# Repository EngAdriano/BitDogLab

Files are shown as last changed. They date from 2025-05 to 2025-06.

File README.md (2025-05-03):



# BitDogLab
An open-source hardware project designed to promote learning in embedded systems, programming, and electronics.

BitDogLab, an initiative of the School Project 4.0 at Unicamp, is an educational tool devoted to electronics and computing. Based on Raspberry Pi Pico H or W, it allows users to explore, assemble, and program using components mounted on its board and also external ones connected in an organized and secure manner. Meticulously selected, the components foster hands-on learning, encouraging users to enhance programming and electronics skills synergistically and progressively. This enriching platform offers a vibrant experience, immersing users in a colourful, auditory, and synesthetic learning environment. Additionally, BitDogLab is optimized for programming assisted by large language models (LLM), like GPT-4, facilitating a more intuitive learning guided by a tireless tutor. Aimed at pre-university education, BitDogLab aims to catalyze the incorporation of educational technology, providing a robust and flexible tool uniquely integrated into students' learning journey.

A hallmark of BitDogLab is that its project is entirely open, allowing it to be freely copied, manufactured, assembled, and improved by users. More information at: https://github.com/Fruett/BitDogLab

This repository holds open-source design files for BitDogLab, an educational STEAM tool. It includes various components like LEDs, buzzers, buttons, and more, promoting collaborative modification and enhancement of STEAM education.

## License
This project is licensed under the CERN Open Hardware Licence Version 2 - Strongly Reciprocal (CERN-OHL-S).
For more details, see the `LICENSE` file or visit [https://cern.ch/cern-ohl](https://cern.ch/cern-ohl).

## Github structure
```bash
├───Firmware "The following files are firmware that should work on BitDogLab"
│   ├───BitDogLab.uf2 "supported on the Raspberry pi pico H version"
│   ├───BitDogLab_W.uf2 "supported on the Raspberry pi pico W (wireless version)"
│   ├───clean.uf2 "Firmware to clean BitDogLab"
│   └───main.py "This is a software example for debug alls board features"
├───kicad "The following files are Hardwares informations"
│   ├───bitdoglab "Schematic, layout and gerber files of DIY version"
│   ├───bitdoglabsmd "Schematic, layout and gerber files of SMD version"
│   └───libs "3D cads, symbols and footprints for bitdoglab DIY"
└───libs "thirdy party libs for softwares"
```

## Firmware v1.0 da BitDogLab with Micropython 1.22.1
### BitDogLab Firmware was compiled on 02/04/2024 and already includes the following 3rd libs:
* ahtx0 (Sensor de temperatura/umidade AHT10 i2c)
* bh1750 (Sensor de luminosidade i2c)
* ssd1306 (Oled i2c)

#### To enter ther bootloader mode, hold bootsel button on the raspberry pi. After, copy the new firmware. If you want to guarantee a new instalation, copy clean.uf2 before.

### [Firmware download](https://github.com/Fruett/BitDogLab/tree/main/Firmware)

## Version 5.4 (DIY)



### Release notes v5.4
* Changing GPIO4 by GPIO10 in Buzzer B
* Changing pin4 GPIO10 by GPIO8 in IDC connector
* Changing pin8 with GPIO8 by GPIO4 in IDC connector
* Changing A,B buttons footprints by 12mm footprint 
* Adding 10k pulldown resistor in batt charging mosfet
### Gerber files for fabrication:
* ADD

### Bill Of material (BOM) for PCB external modules version
* https://docs.google.com/spreadsheets/d/10G9U2lKZ8DwIemRyy8-OiIrZH5e2oOeCSGOkK32-5-8/edit?usp=sharing

## Version 5.3 (PCB SMD version)

SMD PCB version top Side view




SMD PCB version bottom Side view




KiCAD PCB layout: 
* [Panel PCB](https://github.com/Fruett/BitDogLab/blob/main/kicad/bitdoglabsmd/bitdoglab_painel/bitdoglab_painel.kicad_pcb)
* [SMD PCB with Raspberry Pi Pico W](https://github.com/Fruett/BitDogLab/blob/main/kicad/bitdoglabsmd/bitdoglab_main/bitdoglab_smd.kicad_pcb)

Gerber files for fabrication (2024-03-13): 
* [v5.3 panel fabrication files](https://github.com/Fruett/BitDogLab/blob/main/kicad/bitdoglabsmd/bitdoglab_painel/bitdoglab_painel-fabrication-files.zip)
* [v5.3 main fabrication files](https://github.com/Fruett/BitDogLab/blob/main/kicad/bitdoglabsmd/bitdoglab_main/bitdoglab_smd-fabrication-files.zip)

Bill Of material -BOM (2024-03-13): 
* [BOM v5.3 spreadsheet](https://docs.google.com/spreadsheets/d/10G9U2lKZ8DwIemRyy8-OiIrZH5e2oOeCSGOkK32-5-8/edit#gid=1766402277)
* [BOM v5.3 CSV](https://github.com/Fruett/BitDogLab/blob/main/kicad/bitdoglabsmd/bitdoglab_main/bitdoglab_smd.csv)

## Hardware Data Base or Banco de Informação de Hardware
English: https://docs.google.com/document/d/1bf_AKWDJkhcB7H8UVbGR0fSsl2v-2yXr_iV1fd5NWmE/edit?usp=sharing

Português: https://docs.google.com/document/d/13-68OqiU7ISE8U2KPRUXT2ISeBl3WPhXjGDFH52eWlU/edit?usp=sharing

#### Sponsor: IEEE-EDS: https://eds.ieee.org/chapters/programs-and-stem-outreach-resources
#### Sponsor: CNPq - INCT - Namitec: https://web.facebook.com/INCTNAMITEC/?_rdc=1&_rdr
#### Supporter: [Hardware Innovation Technologies (Paulinia/SP/Brazil)](http://www.hwit.com.br/)

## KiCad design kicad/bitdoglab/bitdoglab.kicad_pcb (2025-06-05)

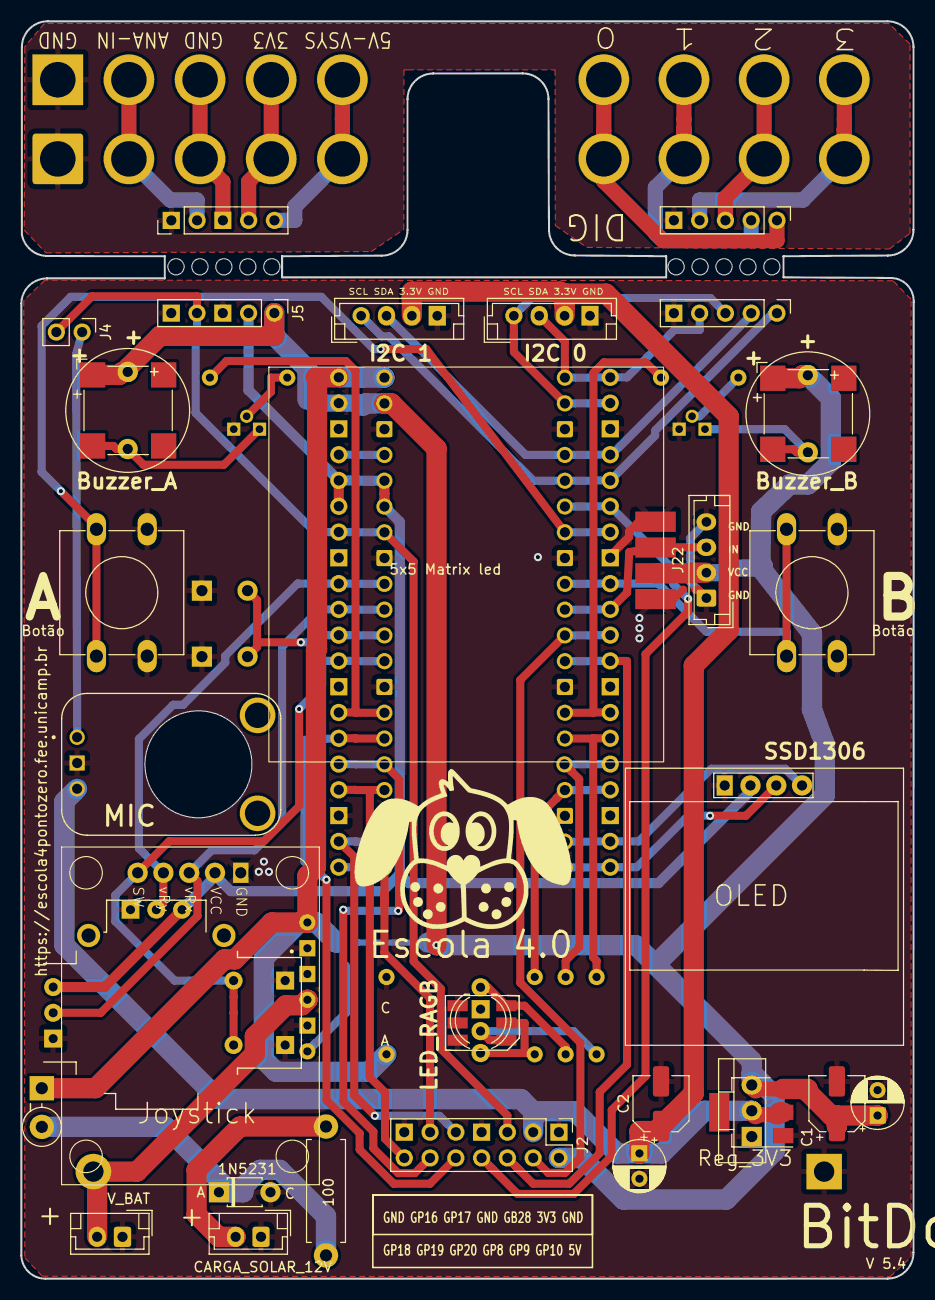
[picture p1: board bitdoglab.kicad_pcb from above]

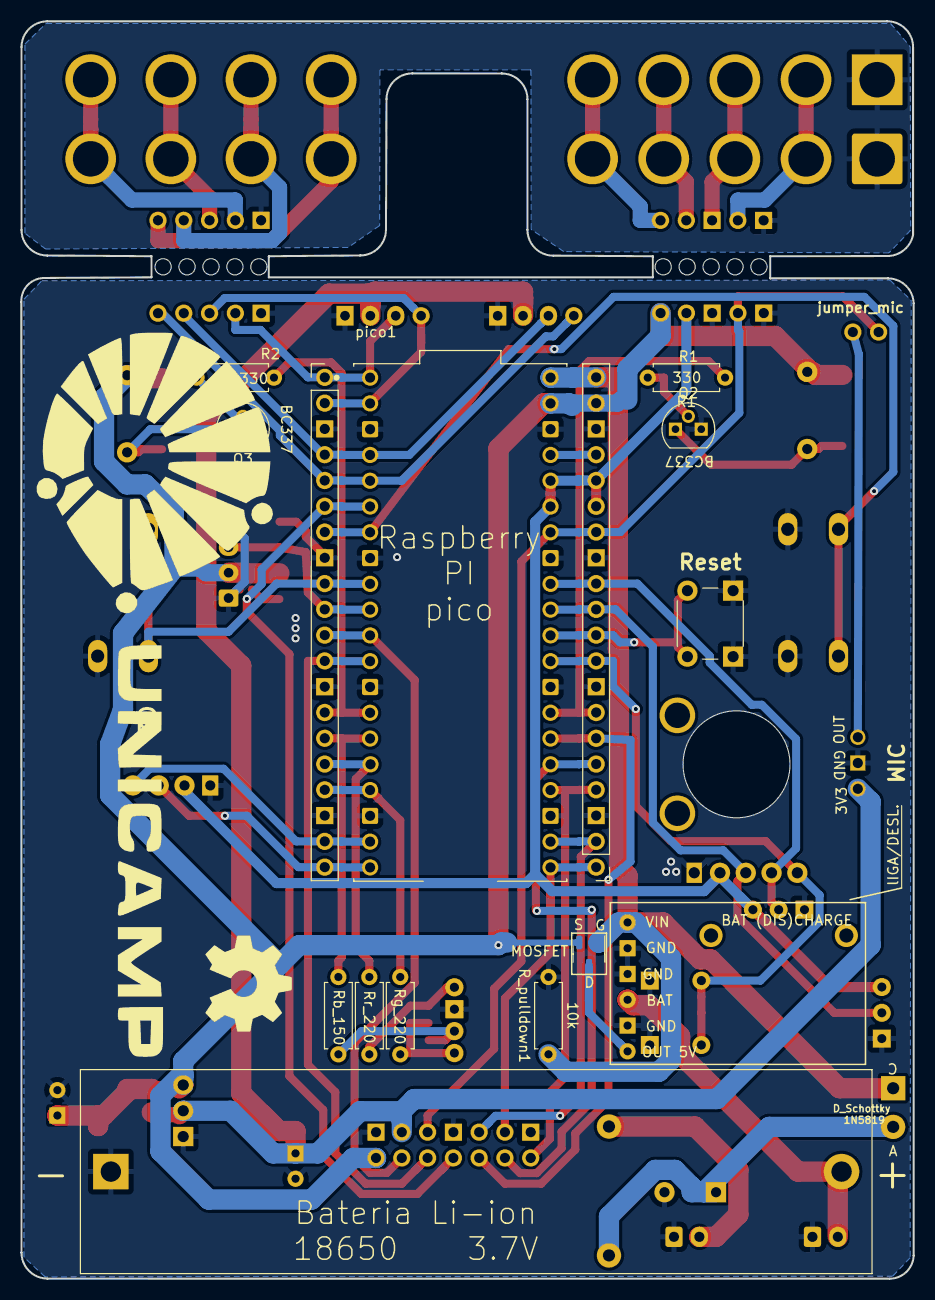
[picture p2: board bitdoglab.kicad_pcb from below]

Board: 2 copper layers, 87.9 x 123.9 mm, 60 parts (17 on the bottom side), 54 nets.

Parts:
BT1: Battery_Cell; BatteryHolder_MPD_BH-18650-PC2
BZ1: Buzzer_A; Buzzer_12x9.5RM7.6
BZ2: Buzzer_A_SMD; MagneticBuzzer_CUI_CMT-8504-100-SMT
BZ3: Buzzer_B; Buzzer_12x9.5RM7.6
BZ4: Buzzer_B_SMD; MagneticBuzzer_CUI_CMT-8504-100-SMT
C1, C2: C_smd; CP_Elec_5x5.9
C3, C4: C_pth; CP_Radial_D5.0mm_P2.50mm
CARGA_SOLAR1: CARGA_SOLAR_12V; JST_EH_B2B-EH-A_1x02_P2.50mm_Vertical
Charge_DisCharge1: BAT (DIS)CHARGE; Charger2A
D1: LED_RGB_SMD; LED_RGB_5050-6
D2: LED_RAGB; LED_D5.0mm-4_RGB_Wide_Pins
D3: 1N5231; D_T-1_P5.08mm_Horizontal
D4: D_Schottky; D_DO-15_P3.81mm_Vertical_KathodeUp
G1: LOGO; logo bitDog 25mm
G2: LOGO; unicamp V2A
G3: LOGO
J1, J3: Conn_01x20_Socket; PinHeader_1x20_P2.54mm_Vertical
J2: conector_idc; PinHeader_2x07_P2.54mm_Vertical
J4: jumper_mic; PinHeader_1x02_P2.54mm_Vertical
J5, J6, J12, J13: Conn_01x05_Pin; PinHeader_1x05_P2.54mm_Vertical
J7, J9: GND; SolderWire-2sqmm_1x02_P7.8mm_D2mm_OD3.9mm
J8: ANA-IN; SolderWire-2sqmm_1x02_P7.8mm_D2mm_OD3.9mm
J10: 3V3; SolderWire-2sqmm_1x02_P7.8mm_D2mm_OD3.9mm
J11: 5V-VSYS; SolderWire-2sqmm_1x02_P7.8mm_D2mm_OD3.9mm
J14: 5x5 Matrix led; Ws2812_led_5050_rgb_5x5
J15: 0; SolderWire-2sqmm_1x02_P7.8mm_D2mm_OD3.9mm
J16: 1; SolderWire-2sqmm_1x02_P7.8mm_D2mm_OD3.9mm
J17: 2; SolderWire-2sqmm_1x02_P7.8mm_D2mm_OD3.9mm
J18: 3; SolderWire-2sqmm_1x02_P7.8mm_D2mm_OD3.9mm
J19: JOYSTICK; ky-023
J20, J21, J22: Conn_01x04_Pin; JST_EH_B4B-EH-A_1x04_P2.50mm_Vertical
JOY1: JOYSTICK; XDCR_COM-09032
OLED1: SSD1306; 128x64OLED
Q1: DMG2305UX-13; SOT-23-3
Q2, Q3: BC337; TO-92
R1, R2: 330; R_Axial_DIN0207_L6.3mm_D2.5mm_P7.62mm_Horizontal
R_1W1: 100; R_Axial_DIN0411_L9.9mm_D3.6mm_P12.70mm_Horizontal
R_pulldown1: 10k; R_Axial_DIN0207_L6.3mm_D2.5mm_P7.62mm_Horizontal
Rb_150: 150; R_Axial_DIN0207_L6.3mm_D2.5mm_P7.62mm_Horizontal
Reg_3V3: 3.3v_smd; SOT-223
Rg_220: 220; R_Axial_DIN0207_L6.3mm_D2.5mm_P7.62mm_Horizontal
Rr_220: 220; R_Axial_DIN0207_L6.3mm_D2.5mm_P7.62mm_Horizontal
SW1: Reset; SW_PUSH_6mm
SW2, SW3: Botão; SW_PUSH-12mm
U1: 3.3v_tht; TO-220-3_Vertical
U4: MIC; MODULE_1063
V_BAT1: V_BAT; JST_EH_B2B-EH-A_1x02_P2.50mm_Vertical
pico1: SC0918; MODULE_SC0918

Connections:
3.3_OUT: J3.15, J3.16, J5.2, J19.2, JOY1.H1, JOY1.V1, OLED1.2 (VCC), pico1.35 (ADC_VREF), pico1.36 (3V3_OUT)
3.3_OUT_EXT: J6.4, J10.1, J10.2
+3.3V: C2.1, C4.1, J2.3, J20.3, J21.3, Reg_3V3.2 (VO), U1.2, U4.3 (VCC)
/AGND_EXT: J6.3, J9.1, J9.2
/GND_EXT: J6.1, J7.1, J7.2, J13.5
/GP0: J1.1, J12.4, J21.2, pico1.1 (GP0)
/GP0_EXT: J13.4, J18.1, J18.2
/GP01: J1.2, J12.3, J21.1, pico1.2 (GP1)
/GP01_EXT: J13.3, J17.1, J17.2
/GP02: J1.4, J12.2, J20.2, pico1.4 (GP2)
/GP02_EXT: J13.2, J16.1, J16.2
/GP03: J1.5, J12.1, J20.1, pico1.5 (GP3)
/GP03_EXT: J13.1, J15.1, J15.2
/GP04: J1.6, J2.8, pico1.6 (GP4)
/GP08: J1.11, J2.4, pico1.11 (GP8)
/GP09: J1.12, J2.6, pico1.12 (GP9)
/GP10: J1.14, R2.1, pico1.14 (GP10)
/GP11: J1.15, Rb_150.2, pico1.15 (GP11)
/GP12: J1.16, Rr_220.2, pico1.16 (GP12)
/GP13: J1.17, Rg_220.2, pico1.17 (GP13)
/GP16: J2.11, J3.1, pico1.21 (GP16)
/GP17: J2.9, J3.2, pico1.22 (GP17)
/GP18: J2.14, J3.4, pico1.24 (GP18)
/GP19: J2.12, J3.5, pico1.25 (GP19)
/GP20: J2.10, J3.6, pico1.26 (GP20)
/GP28: J2.5, J3.14, J4.2, J5.4, pico1.34 (GP28)
/GP28_EXT: J6.2, J8.1, J8.2
/in: J1.10, J14.2, J22.3, pico1.10 (GP7)
/pino_07: J1.7, SW2.1, pico1.7 (GP5)
/pino_09: J1.9, SW3.1, pico1.9 (GP6)
/pino_19: J1.19, OLED1.4 (SDA), pico1.19 (GP14)
/pino_20: J1.20, OLED1.3 (SCL), pico1.20 (GP15)
/pino_27: J3.7, R1.1, pico1.27 (GP21)
/pino_29: J3.9, J19.5, JOY1.B2A, JOY1.B2B, pico1.29 (GP22)
/pino_30: J3.10, SW1.1, pico1.30 (RUN)
/pino_31: J3.11, J19.3, JOY1.H2, pico1.31 (GP26)
/pino_32: J3.12, J19.4, JOY1.V2, pico1.32 (GP27)
/pino_37: J3.17, pico1.37 (3V3_EN)
GNDREF: BT1.2 (-), C1.2, C2.2, C3.2, C4.2, CARGA_SOLAR1.1, Charge_DisCharge1.2 (GND), Charge_DisCharge1.4 (GND), Charge_DisCharge1.5 (GND), D1.1 (RK), D1.2 (GK), D1.3 (BK), D2.2 (K), D3.2 (A), J1.3, J1.8, J1.13, J1.18, J2.1, J2.7, J2.13, J3.3, J3.8, J3.13, J3.18, J5.3, J5.5, J12.5, J14.1, J14.4, J19.1, J20.4, J21.4, J22.1, J22.4, JOY1.B1A, JOY1.B1B, JOY1.H3, JOY1.V3, OLED1.1 (GND), Q2.3 (E), Q3.3 (E), R_pulldown1.2, Reg_3V3.1 (ADJ), SW1.2, SW2.2, SW3.2, U1.1, U4.2 (GND), V_BAT1.1, pico1.3 (GND), pico1.8 (GND), pico1.13 (GND), pico1.18 (GND), pico1.23 (GND), pico1.28 (GND), pico1.33 (AGND), pico1.38 (GND)
unnamed: BZ1.2 (+), BZ2.2 (+), Q2.1 (C)
unnamed: BZ3.2 (+), BZ4.2 (+), Q3.1 (C)
unnamed: CARGA_SOLAR1.2, R_1W1.2
unnamed: Charge_DisCharge1.1 (OUT5V), Q1.3 (D)
unnamed: D1.4 (BA), D2.3 (BA), Rb_150.1
unnamed: D1.5 (GA), D2.4 (GA), Rg_220.1
unnamed: D1.6 (RA), D2.1 (RA), Rr_220.1
unnamed: D3.1 (K), D4.2 (A), R_1W1.1
unnamed: J4.1, U4.1 (OUT)
unnamed: Q2.2 (B), R1.2
unnamed: Q3.2 (B), R2.2
VBUS: Charge_DisCharge1.6 (VIN), D4.1 (K), J3.20, Q1.1 (G), R_pulldown1.1, pico1.40 (VBUS)
VSYS: BZ1.1 (-), BZ2.1 (-), BZ3.1 (-), BZ4.1 (-), C1.1, C3.1, J2.2, J3.19, J5.1, J14.3, J22.2, Q1.2 (S), Reg_3V3.3 (VI), U1.3, pico1.39 (VSYS)
VSYS_EXT: J6.5, J11.1, J11.2
V_BAT +: BT1.1 (+), Charge_DisCharge1.3 (BAT), V_BAT1.2

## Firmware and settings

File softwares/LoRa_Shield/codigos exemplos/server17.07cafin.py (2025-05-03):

from machine import Pin, SoftI2C,PWM
from time import sleep
from ulora import LoRa, ModemConfig, SPIConfig
from ssd1306 import SSD1306_I2C
import os
import time
#configuração do OLED
i2c = SoftI2C(scl = Pin(15),sda = Pin(14))
oled = SSD1306_I2C(128,64,i2c)

#LoRa parameters
RFM95_RST = 28 # pino reset lora
RFM95_SPIBUS = SPIConfig.rp2_0 # pinagem LoRa RM95 e Pico
RFM95_CS = 17 # Chip select
RFM95_INT = 20 # DIO0
RF95_FREQ = 915.0 # Frequencia de transmissao
RF95_POW = 20 # Potencia de transmissao
CLIENT_ADDRESS = 1 # endereço cliente
SERVER_ADDRESS =2 # endereço server
#função para receber os dados da comunicação LoRa
#arquivo para salvar as informações
verde = Pin(11, Pin.OUT) # verde
azul = Pin(12, Pin.OUT) # azul
vermelho = Pin(13, Pin.OUT) #vermelho

buzzer_pin = Pin(21, Pin.OUT)
buzzer_pwm = PWM(buzzer_pin)
ex_notes = [
    330, 262, 523]
note_duration = [
    100, 100, 100]
# Função para tocar a música tema de Star Wars
def play_ex_notes():
    for i, note in enumerate(ex_notes):
        if note == 0:
            buzzer_pwm.duty_u16(0)
        else:
            buzzer_pwm.freq(note)
            buzzer_pwm.duty_u16(32768)  # 50% de duty cycle
        time.sleep_ms(note_duration[i])

try:
    play_ex_notes()  # Chama a função para tocar a música tema de Star Wars
finally:
    buzzer_pwm.deinit()  # Desliga o PWM do buzzer quando o programa terminar
    
def on_recv(payload):
    print("From: ",payload.header_from)
    print("Received: ",payload.message)
    print("RSSI: {}, SNR: {}".format(payload.rssi, payload.snr))
    #message = payload.message.decode('utf-8')
    oled.fill(0)  # Limpar oled
    oled.text(f"Testando o lora", 20, 0, 1)
    oled.text(f"From: {payload.header_from}", 0, 10, 1)
    oled.text(f"Received: {payload.message}", 0, 20, 1)
    oled.text(f"{payload.message}", 0, 30, 2)
    oled.text(f"RSSI: {payload.rssi}", 0, 40, 1)
    oled.text(f"SNR: {type(payload.message)}", 0, 50, 1)
    oled.show()

    if payload.message == b'1':
        vermelho.on()
        verde.off()
        azul.off()

    if payload.message == b'2':
        vermelho.off()
        verde.on()
        azul.off()
    
    if payload.message == b'3':
        vermelho.off()
        verde.off()
        azul.on()
        play_ex_notes()
    
    if payload.message == b'4':
        vermelho.off()
        verde.off()
        azul.off()
        
        buzzer_pwm.duty_u16(0)



# initialize radio LoRa
lora = LoRa(RFM95_SPIBUS,RFM95_INT,SERVER_ADDRESS,RFM95_CS,reset_pin = RFM95_RST,freq =RF95_FREQ, tx_power =RF95_POW,acks = True)
lora.on_recv = on_recv
lora.set_mode_rx() # modo de recebimento continuo

#Botoes
botao_a = Pin(5,Pin.IN, Pin.PULL_UP)
botao_b = Pin(6,Pin.IN, Pin.PULL_UP)


oled.text("BitDogLab",0,0,1)
oled.show()


while True:
    sleep(0.1)

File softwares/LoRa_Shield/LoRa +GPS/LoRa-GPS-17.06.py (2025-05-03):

from machine import Pin, UART, I2C
import utime
from ssd1306 import SSD1306_I2C
from micropyGPS import MicropyGPS
from ulora import LoRa, ModemConfig,SPIConfig
from time import sleep
#LoRa parameters
RFM95_RST = 28 # pino reset lora
RFM95_SPIBUS = SPIConfig.rp2_0 # pinagem LoRa RM95 e Pico
RFM95_CS = 17 # Chip select
RFM95_INT = 20 # DIO0
RF95_FREQ = 868.0 # Frequencia de transmissao
RF95_POW = 10 # Potencia de transmissao
CLIENT_ADDRESS = 1 # endereço cliente
SERVER_ADDRESS =2 # endereço server

# initialize radio LoRa
lora = LoRa(RFM95_SPIBUS,RFM95_INT,CLIENT_ADDRESS,RFM95_CS,reset_pin = RFM95_RST,freq =RF95_FREQ, tx_power =RF95_POW,acks = True)

#Inicializa I2C e display oled
i2c = I2C(1,sda =Pin(14),scl=Pin(15),freq=400000)
oled = SSD1306_I2C(128,64,i2c)

# Inicializa GPS
gps_module = UART(0,baudrate=9600, tx=Pin(0),rx=Pin(1))
time_zone = -3 # fuso horario
gps = MicropyGPS(time_zone) # ajuste de time zone
 
#Botoes
botao_a = Pin(5,Pin.IN, Pin.PULL_UP)
botao_b = Pin(6,Pin.IN, Pin.PULL_UP)

def msg(text=''):
    lora.send_to_wait(f"{text}",SERVER_ADDRESS)

def convert_coordinates(sections):
    if sections[0] == 0:
        return None
    
    data = sections[0] +(sections[1]/60.0)

    if sections[2] == 'S':
        data = -data
    if sections[2] == 'W':
        data = -data

    data = '{0:.6f}'.format(data)
    return str(data) # retorna  o dado no formato string

while True:
    length = gps_module.any()
    if length >0:
        data = gps_module.read(length)
        for byte in data:
            message = gps.update(chr(byte))

    latitude = convert_coordinates(gps.latitude)
    longitude = convert_coordinates(gps.longitude)
    altitude = gps.altitude # obtendo a altitude do gps
    hora = gps.timestamp 
    date = gps.date

    if latitude is None or longitude is None:
        oled.fill(0)
        oled.text('Data unavailable',0,10)
        oled.text('No coordinates',22,40)
        oled.show()
        continue

    #formatando data e hora
    date_str = f"{int(date[0])}/{int(date[1]):02d}/{int(date[2]):02d}"
    time_str = f"{int(hora[0]):02d}:{int(hora[1]):02d}:{int(hora[2]):02d}"
    oled.fill(0)
    oled.text('Satelites: '+ str(gps.satellites_in_use),10,0)
    oled.text('Lat: ' + latitude,0,18)
    oled.text('Long: '+ longitude,0,36)
    oled.text('Alt: '+ str(altitude) + 'm',0,54)
    oled.text(date_str,0,72)
    oled.text(time_str,0,90)
    print('Long: ' + longitude)
    print('Lat: ' + latitude)
    print('Alt: ' + str(altitude))
    print('Date: ',date_str)
    print('Hora: ',time_str)
    data_gps=(f"{latitude},{longitude},{altitude},{date_str},{time_str}")
    oled.show()
   # msg(data_gps)
    

    if botao_a.value() == 0:
        oled.fill(0)
        oled.text(f"coordinates send", 0, 50, 1)
        oled.show()
        msg(data_gps)

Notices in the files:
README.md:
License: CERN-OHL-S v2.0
